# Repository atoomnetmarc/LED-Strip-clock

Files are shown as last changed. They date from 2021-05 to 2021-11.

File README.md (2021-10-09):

# Status

This project is in the idea stage.

Next step would be to test if the new schematic could work before ordering the first PCB.

# Why?

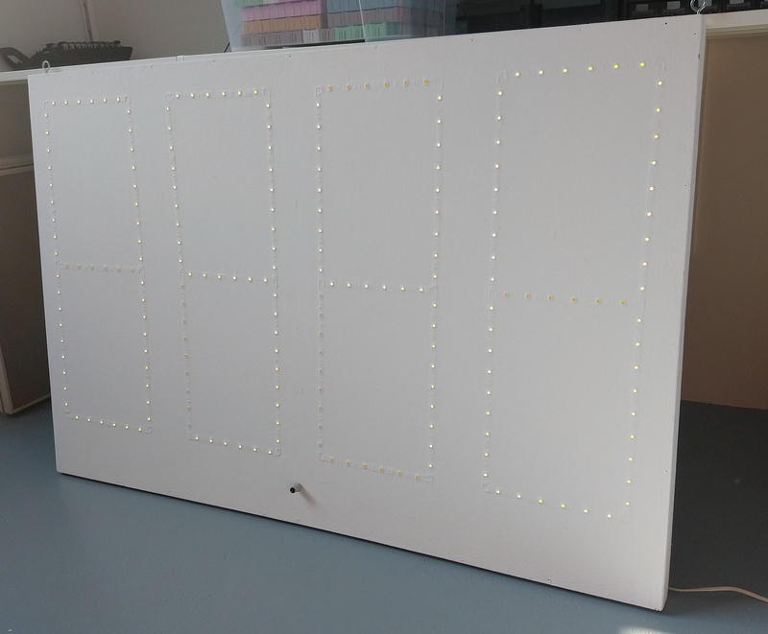
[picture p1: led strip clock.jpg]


I made a huge LED clock with pieces of LED strip in 2013 using an [ATmega328 and DS3231 RTC](ATmega328%20version/). It has been running great and keeping time just fine. Lets break it by upgrading it.

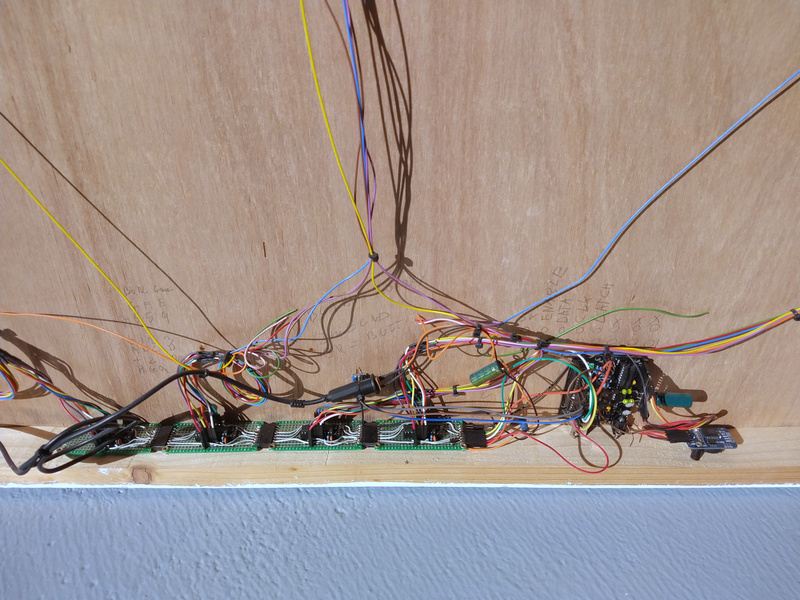
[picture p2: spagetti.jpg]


This project will upgrade the ~~spagetti~~ old circuit to an internet connected LED strip clock neatly on a PCB. The brains will be a Wemos D1 mini and will use NTP to synchronize the time.

# Schematic

The [circuit](Kicad/LED%20Strip%20clock.pdf) recycles the same TPIC6B595 power shift registers and changes the ATmega328 for a ESP8266 and the DS3231 for a DS3231MZ. A 74HCT244 buffer translates between the 3.3V outputs of the ESP8266 and the 5V inputs of the shift register. The original circuit has a rotary encoder to set the light intensity and the current time. The new circuit will only use the rotary encoder to set the light intensity.

Render:

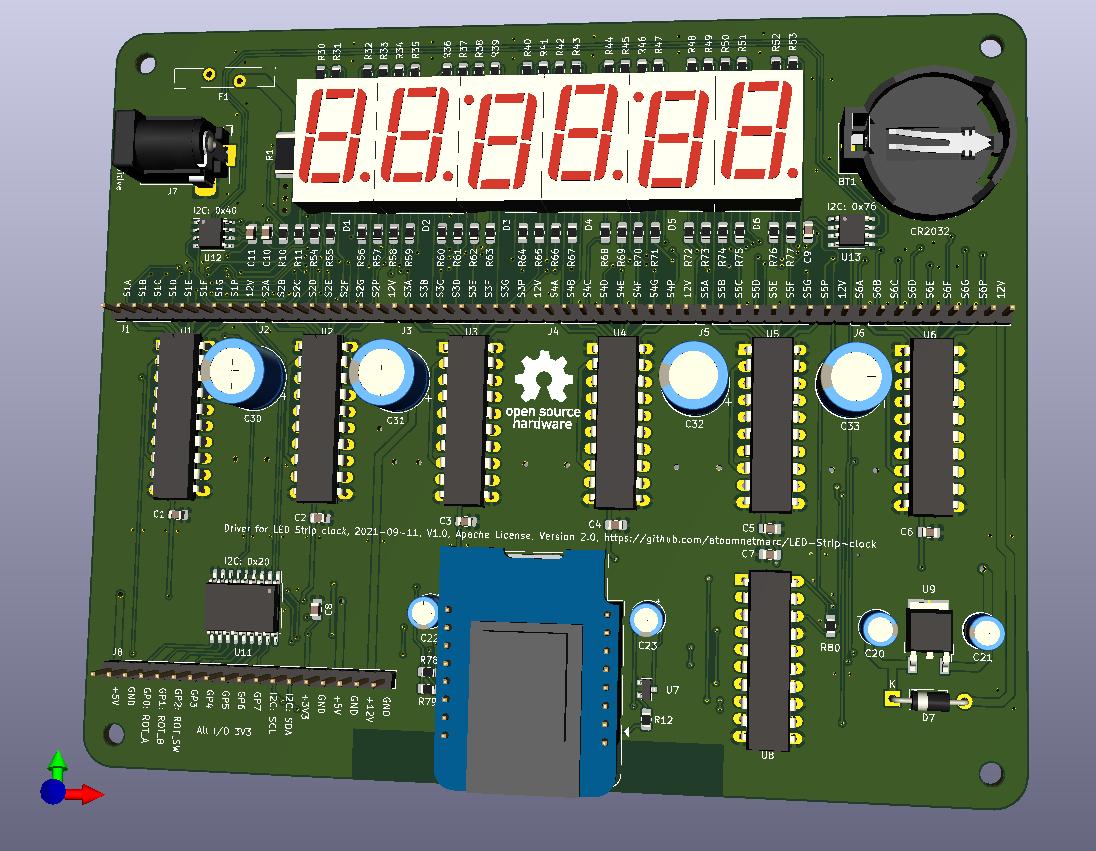
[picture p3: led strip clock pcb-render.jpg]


Real:

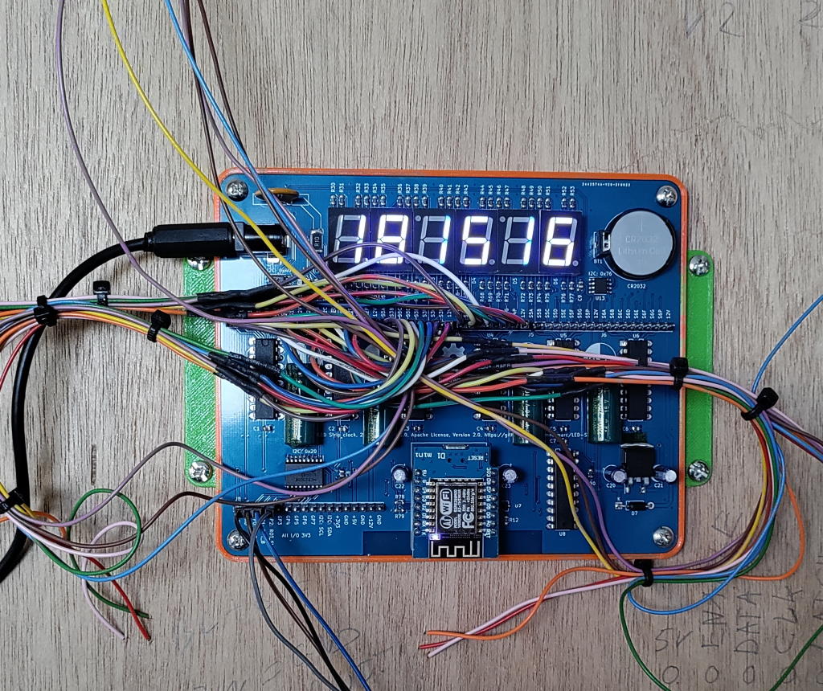
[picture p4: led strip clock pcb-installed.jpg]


My [Kicad library](https://github.com/atoomnetmarc/ATOOMNETKICAD) is used in this project.



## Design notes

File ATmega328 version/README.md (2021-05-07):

**Status**: archived.

This is ye olde code that ran on the ATmega328 board with a DS3231 RTC made in [Atmel studio 6.1](https://www.microchip.com/mplab/avr-support/avr-and-sam-downloads-archive).

# License

Please inspect the individual source files for their respective licenses.

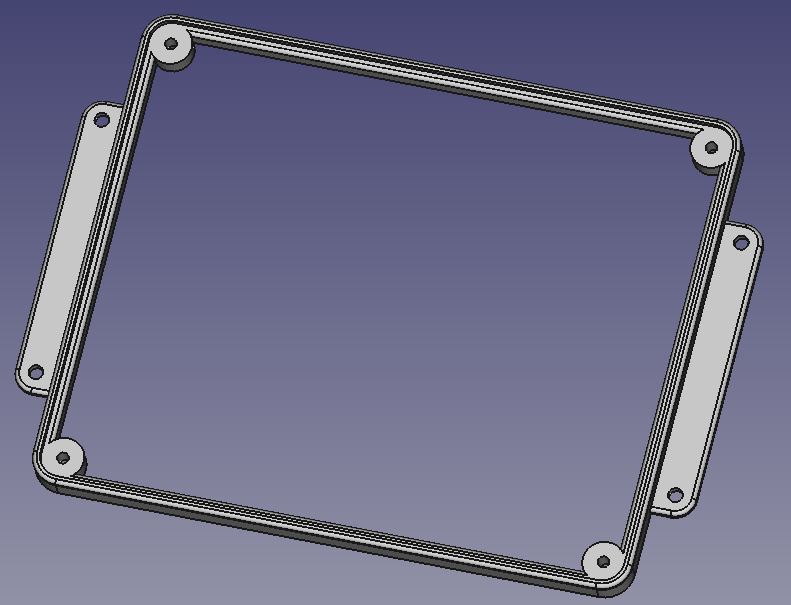
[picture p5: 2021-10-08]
3d/pcb holder.png

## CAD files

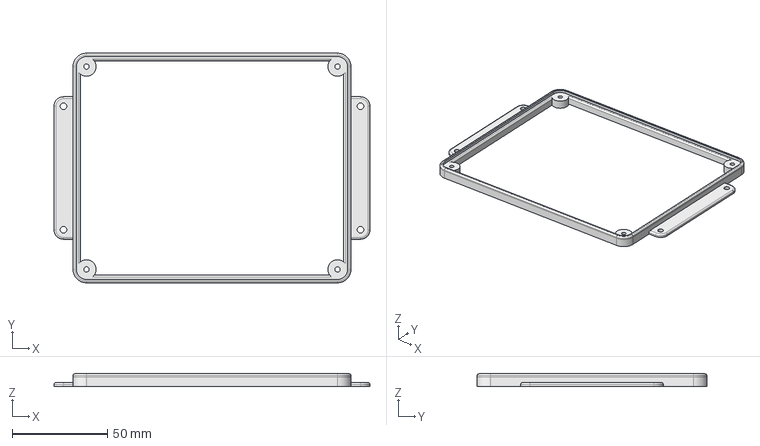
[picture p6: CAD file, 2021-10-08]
3d/pcb holder.FCStd
166.2 x 120.8 x 6.60 mm

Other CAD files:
3d/pcb holder.stl

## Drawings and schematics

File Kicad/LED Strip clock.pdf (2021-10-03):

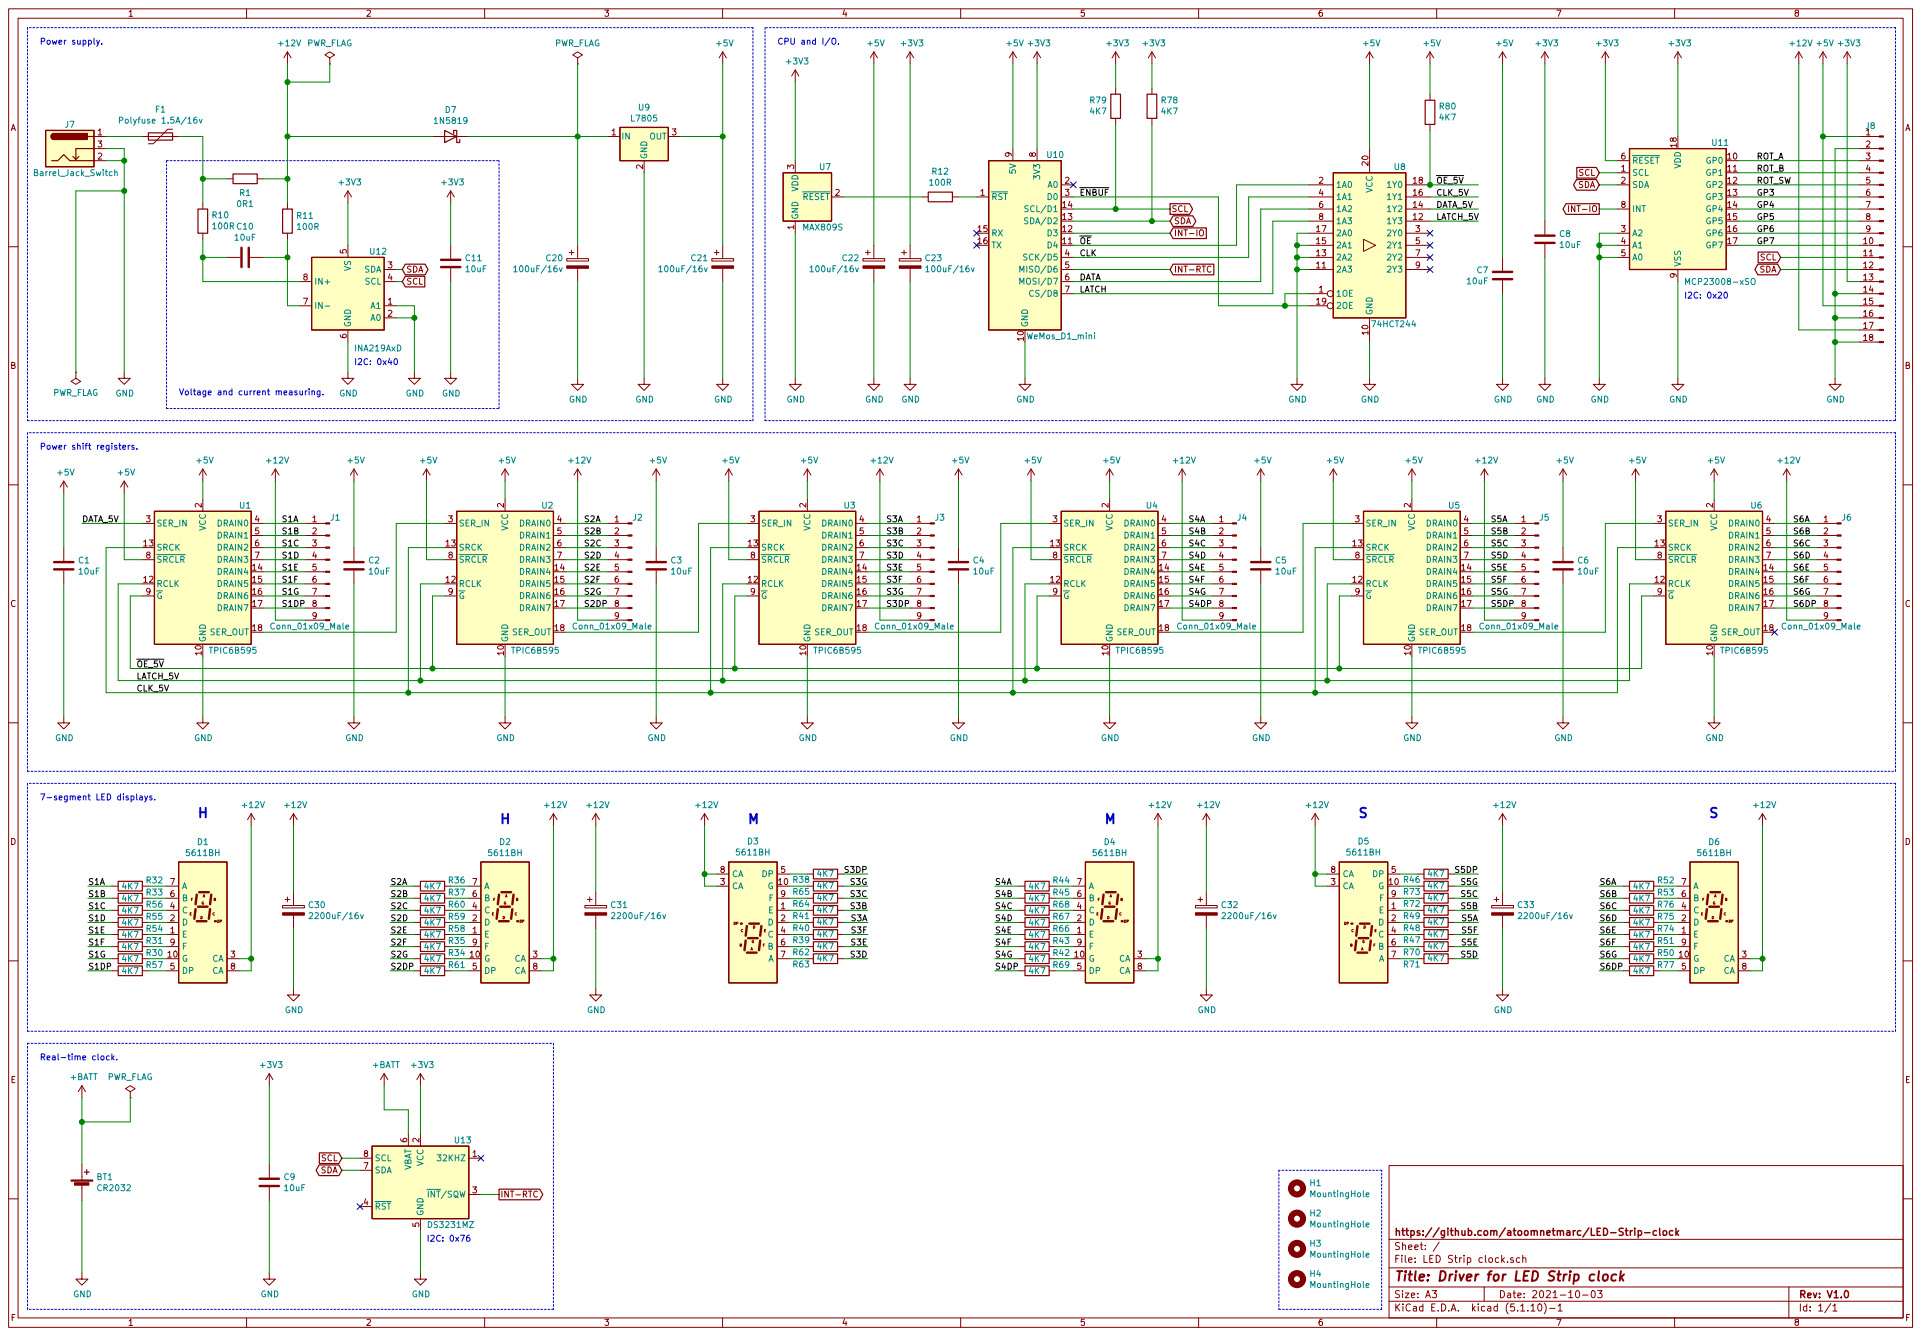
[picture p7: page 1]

Voltage and current measuring.

File: LED Strip clock.sch Sheet: / https://github.com/atoomnetmarc/LED-Strip-clock

Id: 1/1 Title: Driver for LED Strip clock

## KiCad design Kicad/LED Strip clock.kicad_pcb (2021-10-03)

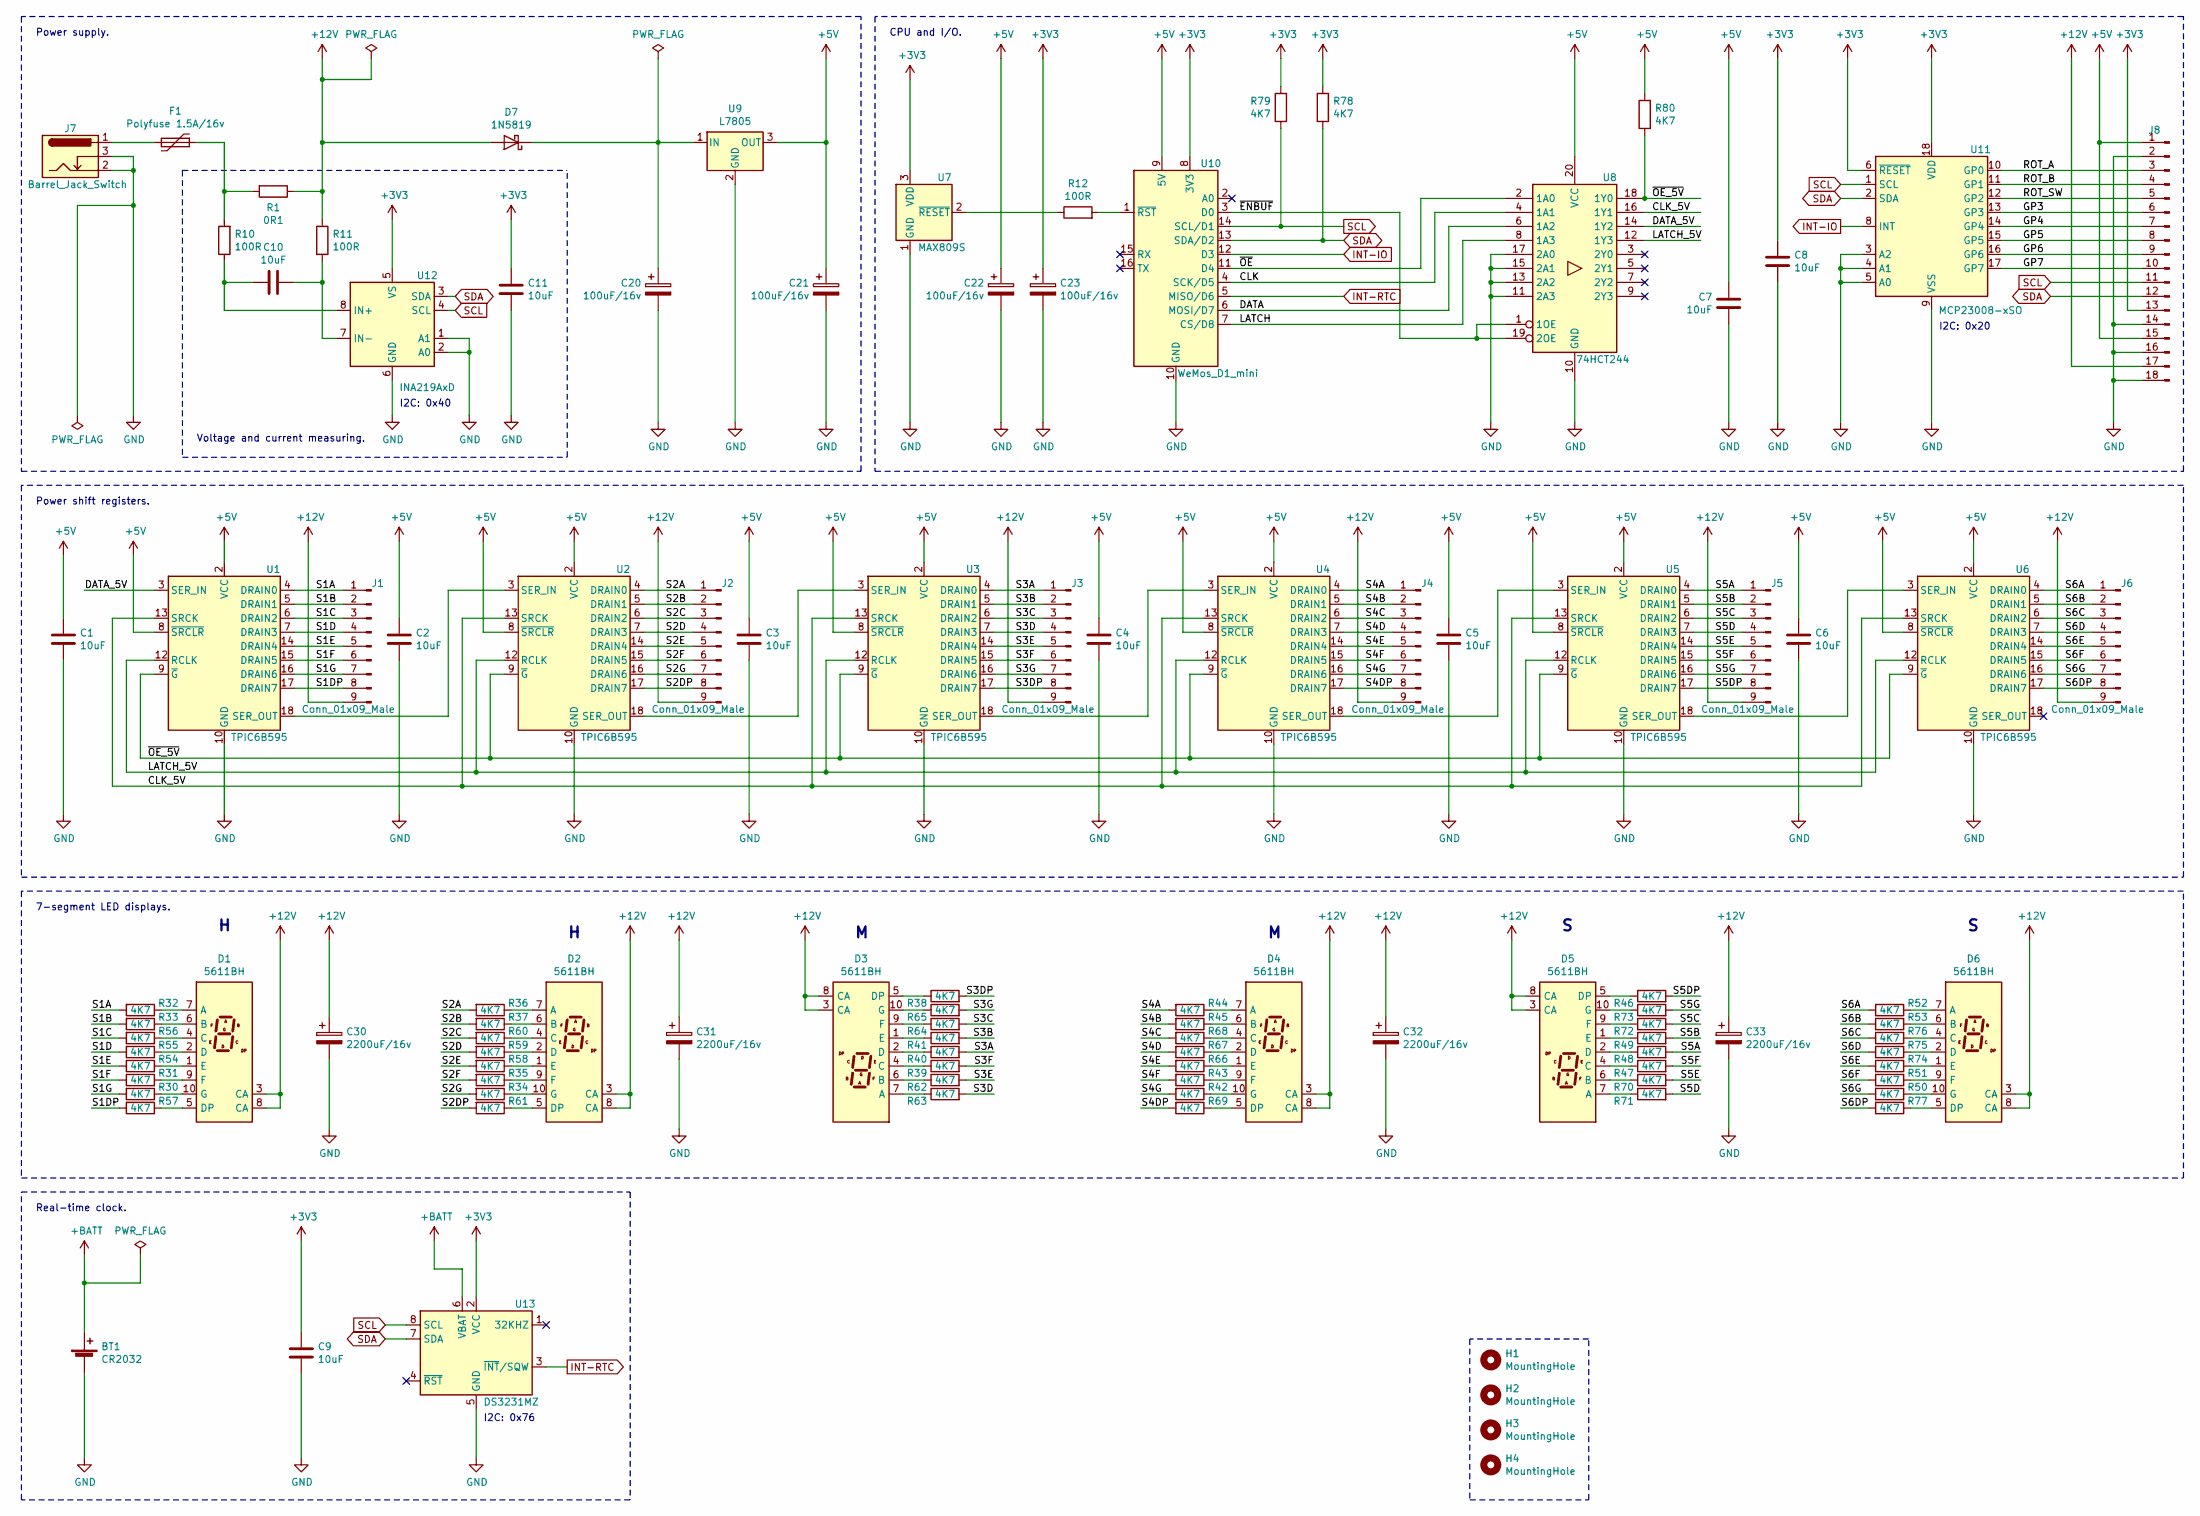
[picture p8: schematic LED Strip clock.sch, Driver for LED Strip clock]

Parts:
BT1: CR2032; BatteryHolder-cr2032
C1, C2, C3, C4, C5, C6, C7, C8, C9, C10, C11: 10uF; C_0805_2012Metric_Pad1.18x1.45mm_HandSolder
C20, C21, C22, C23: 100uF/16v; CP_Radial_D5.0mm_P2.00mm
C30, C31, C32, C33: 2200uF/16v; CP_Radial_D10.0mm_P5.00mm
D1, D2, D3, D4, D5, D6: 5611BH
D7: 1N5819; D_DO-41_SOD81_P10.16mm_Horizontal
F1: Polyfuse 1.5A/16v; Fuse_Bourns_MF-RG1000
H1, H2, H3, H4: MountingHole; MountingHole_3.2mm_M3
J1, J2, J3, J4, J5, J6: Conn_01x09_Male; PinHeader_1x09_P2.54mm_Vertical
J7: Barrel_Jack_Switch; BarrelJack_Horizontal
J8: Conn_01x18_Male; PinHeader_1x18_P2.54mm_Vertical
R1: 0R1; R_2512_6332Metric_Pad1.52x3.35mm_HandSolder
R10, R11, R12: 100R; R_0805_2012Metric_Pad1.20x1.40mm_HandSolder
R30, R31, R32, R33, R34, R35, R36, R37, R38, R39, R40, R41, R42, R43, R44, R45, R46, R47, R48, R49, R50, R51, R52, R53, R54, R55, R56, R57, R58, R59, R60, R61, R62, R63, R64, R65, R66, R67, R68, R69, R70, R71, R72, R73, R74, R75, R76, R77, R78, R79, R80: 4K7; R_0805_2012Metric_Pad1.20x1.40mm_HandSolder
U1, U2, U3, U4, U5, U6: TPIC6B595; DIP-20_W7.62mm_LongPads
U7: MAX809S; SOT-23
U8: 74HCT244; DIP-20_W7.62mm_LongPads
U9: L7805; TO-263-2
U10: WeMos_D1_mini; WEMOS_D1_mini_light
U11: MCP23008-xSO; SOIC-18W_7.5x11.6mm_P1.27mm
U12: INA219AxD; SOIC-8_3.9x4.9mm_P1.27mm
U13: DS3231MZ; SOIC-8_3.9x4.9mm_P1.27mm

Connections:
+3V3: C8.1, C9.1, C11.1, C23.1, J8.13, R78.2, R79.2, U7.3 (VDD), U10.8 (3V3), U11.6 (~RESET), U11.18 (VDD), U12.5 (VS), U13.2 (VCC)
+5V: C1.1, C2.1, C3.1, C4.1, C5.1, C6.1, C7.1, C21.1, C22.1, J8.1, J8.15, R80.2, U1.2 (VCC), U1.8 (~SRCLR), U2.2 (VCC), U2.8 (~SRCLR), U3.2 (VCC), U3.8 (~SRCLR), U4.2 (VCC), U4.8 (~SRCLR), U5.2 (VCC), U5.8 (~SRCLR), U6.2 (VCC), U6.8 (~SRCLR), U8.20 (VCC), U9.3 (OUT), U10.9 (5V)
+12V: C30.1, C31.1, C32.1, C33.1, D1.3 (CA), D1.8 (CA), D2.3 (CA), D2.8 (CA), D3.3 (CA), D3.8 (CA), D4.3 (CA), D4.8 (CA), D5.3 (CA), D5.8 (CA), D6.3 (CA), D6.8 (CA), D7.2 (A), J1.9, J2.9, J3.9, J4.9, J5.9, J6.9, J8.17, R1.1, R11.1
+BATT: BT1.1 (+), U13.6 (VBAT)
/CLK: U8.4 (1A1), U10.4 (SCK/D5)
/CLK_5V: U1.13 (SRCK), U2.13 (SRCK), U3.13 (SRCK), U4.13 (SRCK), U5.13 (SRCK), U6.13 (SRCK), U8.16 (1Y1)
/DATA: U8.6 (1A2), U10.6 (MOSI/D7)
/DATA_5V: U1.3 (SER_IN), U8.14 (1Y2)
/GP3: J8.6, U11.13 (GP3)
/GP4: J8.7, U11.14 (GP4)
/GP5: J8.8, U11.15 (GP5)
/GP6: J8.9, U11.16 (GP6)
/GP7: J8.10, U11.17 (GP7)
/LATCH: U8.8 (1A3), U10.7 (CS/D8)
/LATCH_5V: U1.12 (RCLK), U2.12 (RCLK), U3.12 (RCLK), U4.12 (RCLK), U5.12 (RCLK), U6.12 (RCLK), U8.12 (1Y3)
/ROT_A: J8.3, U11.10 (GP0)
/ROT_B: J8.4, U11.11 (GP1)
/ROT_SW: J8.5, U11.12 (GP2)
/S1A: J1.1, R32.2, U1.4 (DRAIN0)
/S1B: J1.2, R33.2, U1.5 (DRAIN1)
/S1C: J1.3, R56.2, U1.6 (DRAIN2)
/S1D: J1.4, R55.2, U1.7 (DRAIN3)
/S1DP: J1.8, R57.2, U1.17 (DRAIN7)
/S1E: J1.5, R54.2, U1.14 (DRAIN4)
/S1F: J1.6, R31.2, U1.15 (DRAIN5)
/S1G: J1.7, R30.2, U1.16 (DRAIN6)
/S2A: J2.1, R36.2, U2.4 (DRAIN0)
/S2B: J2.2, R37.2, U2.5 (DRAIN1)
/S2C: J2.3, R60.2, U2.6 (DRAIN2)
/S2D: J2.4, R59.2, U2.7 (DRAIN3)
/S2DP: J2.8, R61.2, U2.17 (DRAIN7)
/S2E: J2.5, R58.2, U2.14 (DRAIN4)
/S2F: J2.6, R35.2, U2.15 (DRAIN5)
/S2G: J2.7, R34.2, U2.16 (DRAIN6)
/S3A: J3.1, R40.2, U3.4 (DRAIN0)
/S3B: J3.2, R41.2, U3.5 (DRAIN1)
/S3C: J3.3, R64.2, U3.6 (DRAIN2)
/S3D: J3.4, R63.2, U3.7 (DRAIN3)
/S3DP: J3.8, R38.2, U3.17 (DRAIN7)
/S3E: J3.5, R62.2, U3.14 (DRAIN4)
/S3F: J3.6, R39.2, U3.15 (DRAIN5)
/S3G: J3.7, R65.2, U3.16 (DRAIN6)
/S4A: J4.1, R44.2, U4.4 (DRAIN0)
/S4B: J4.2, R45.2, U4.5 (DRAIN1)
/S4C: J4.3, R68.2, U4.6 (DRAIN2)
/S4D: J4.4, R67.2, U4.7 (DRAIN3)
/S4DP: J4.8, R69.2, U4.17 (DRAIN7)
/S4E: J4.5, R66.2, U4.14 (DRAIN4)
/S4F: J4.6, R43.2, U4.15 (DRAIN5)
/S4G: J4.7, R42.2, U4.16 (DRAIN6)
/S5A: J5.1, R48.2, U5.4 (DRAIN0)
/S5B: J5.2, R49.2, U5.5 (DRAIN1)
/S5C: J5.3, R72.2, U5.6 (DRAIN2)
/S5D: J5.4, R71.2, U5.7 (DRAIN3)
/S5DP: J5.8, R46.2, U5.17 (DRAIN7)
/S5E: J5.5, R70.2, U5.14 (DRAIN4)
/S5F: J5.6, R47.2, U5.15 (DRAIN5)
/S5G: J5.7, R73.2, U5.16 (DRAIN6)
/S6A: J6.1, R52.2, U6.4 (DRAIN0)
/S6B: J6.2, R53.2, U6.5 (DRAIN1)
/S6C: J6.3, R76.2, U6.6 (DRAIN2)
/S6D: J6.4, R75.2, U6.7 (DRAIN3)
/S6DP: J6.8, R77.2, U6.17 (DRAIN7)
/S6E: J6.5, R74.2, U6.14 (DRAIN4)
/S6F: J6.6, R51.2, U6.15 (DRAIN5)
/S6G: J6.7, R50.2, U6.16 (DRAIN6)
/~ENBUF: U8.1 (1OE), U8.19 (2OE), U10.3 (D0)
/~OE: U8.2 (1A0), U10.11 (D4)
/~OE_5V: R80.1, U1.9 (~G), U2.9 (~G), U3.9 (~G), U4.9 (~G), U5.9 (~G), U6.9 (~G), U8.18 (1Y0)
GND: BT1.2 (-), C1.2, C2.2, C3.2, C4.2, C5.2, C6.2, C7.2, C8.2, C9.2, C11.2, C20.2, C21.2, C22.2, C23.2, C30.2, C31.2, C32.2, C33.2, J7.2, J7.3, J8.2, J8.14, J8.16, J8.18, U1.1 (NC), U1.10 (GND), U1.11 (GND), U1.19 (GND), U1.20 (NC), U2.1 (NC), U2.10 (GND), U2.11 (GND), U2.19 (GND), U2.20 (NC), U3.1 (NC), U3.10 (GND), U3.11 (GND), U3.19 (GND), U3.20 (NC), U4.1 (NC), U4.10 (GND), U4.11 (GND), U4.19 (GND), U4.20 (NC), U5.1 (NC), U5.10 (GND), U5.11 (GND), U5.19 (GND), U5.20 (NC), U6.1 (NC), U6.10 (GND), U6.11 (GND), U6.19 (GND), U6.20 (NC), U7.1 (GND), U8.10 (GND), U8.11 (2A3), U8.13 (2A2), U8.15 (2A1), U8.17 (2A0), U9.2 (GND), U10.10 (GND), U11.3 (A2), U11.4 (A1), U11.5 (A0), U11.9 (VSS), U12.1 (A1), U12.2 (A0), U12.6 (GND), U13.5 (GND)
INT-IO: U10.12 (D3), U11.8 (INT)
INT-RTC: U10.5 (MISO/D6), U13.3 (~INT~/SQW)
unnamed: C10.1, R10.1, U12.8 (IN+)
unnamed: C10.2, R11.2, U12.7 (IN-)
unnamed: C20.1, D7.1 (K), U9.1 (IN)
unnamed: D1.1 (E), R54.1
unnamed: D1.2 (D), R55.1
unnamed: D1.4 (C), R56.1
unnamed: D1.5 (DP), R57.1
unnamed: D1.6 (B), R33.1
unnamed: D1.7 (A), R32.1
unnamed: D1.9 (F), R31.1
unnamed: D1.10 (G), R30.1
unnamed: D2.1 (E), R58.1
unnamed: D2.2 (D), R59.1
unnamed: D2.4 (C), R60.1
unnamed: D2.5 (DP), R61.1
unnamed: D2.6 (B), R37.1
unnamed: D2.7 (A), R36.1
unnamed: D2.9 (F), R35.1
unnamed: D2.10 (G), R34.1
unnamed: D3.1 (E), R41.1
unnamed: D3.2 (D), R40.1
unnamed: D3.4 (C), R39.1
unnamed: D3.5 (DP), R38.1
unnamed: D3.6 (B), R62.1
unnamed: D3.7 (A), R63.1
unnamed: D3.9 (F), R64.1
unnamed: D3.10 (G), R65.1
unnamed: D4.1 (E), R66.1
unnamed: D4.2 (D), R67.1
unnamed: D4.4 (C), R68.1
unnamed: D4.5 (DP), R69.1
unnamed: D4.6 (B), R45.1
unnamed: D4.7 (A), R44.1
unnamed: D4.9 (F), R43.1
unnamed: D4.10 (G), R42.1
unnamed: D5.1 (E), R49.1
unnamed: D5.2 (D), R48.1
unnamed: D5.4 (C), R47.1
unnamed: D5.5 (DP), R46.1
unnamed: D5.6 (B), R70.1
unnamed: D5.7 (A), R71.1
unnamed: D5.9 (F), R72.1
unnamed: D5.10 (G), R73.1
unnamed: D6.1 (E), R74.1
unnamed: D6.2 (D), R75.1
unnamed: D6.4 (C), R76.1
unnamed: D6.5 (DP), R77.1
unnamed: D6.6 (B), R53.1
unnamed: D6.7 (A), R52.1
unnamed: D6.9 (F), R51.1
unnamed: D6.10 (G), R50.1
unnamed: F1.1, R1.2, R10.2
unnamed: F1.2, J7.1
unnamed: R12.1, U7.2 (~RESET)
unnamed: R12.2, U10.1 (~RST)
unnamed: U1.18 (SER_OUT), U2.3 (SER_IN)
unnamed: U2.18 (SER_OUT), U3.3 (SER_IN)
unnamed: U3.18 (SER_OUT), U4.3 (SER_IN)
unnamed: U4.18 (SER_OUT), U5.3 (SER_IN)
unnamed: U5.18 (SER_OUT), U6.3 (SER_IN)
SCL: J8.11, R79.1, U10.14 (SCL/D1), U11.1 (SCL), U12.4 (SCL), U13.8 (SCL)
SDA: J8.12, R78.1, U10.13 (SDA/D2), U11.2 (SDA), U12.3 (SDA), U13.7 (SDA)

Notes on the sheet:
I2C: 0x40
I2C: 0x20
Voltage and current measuring.
Power supply.
CPU and I/O.
Power shift registers.
7-segment LED displays.
Real-time clock.
I2C: 0x76

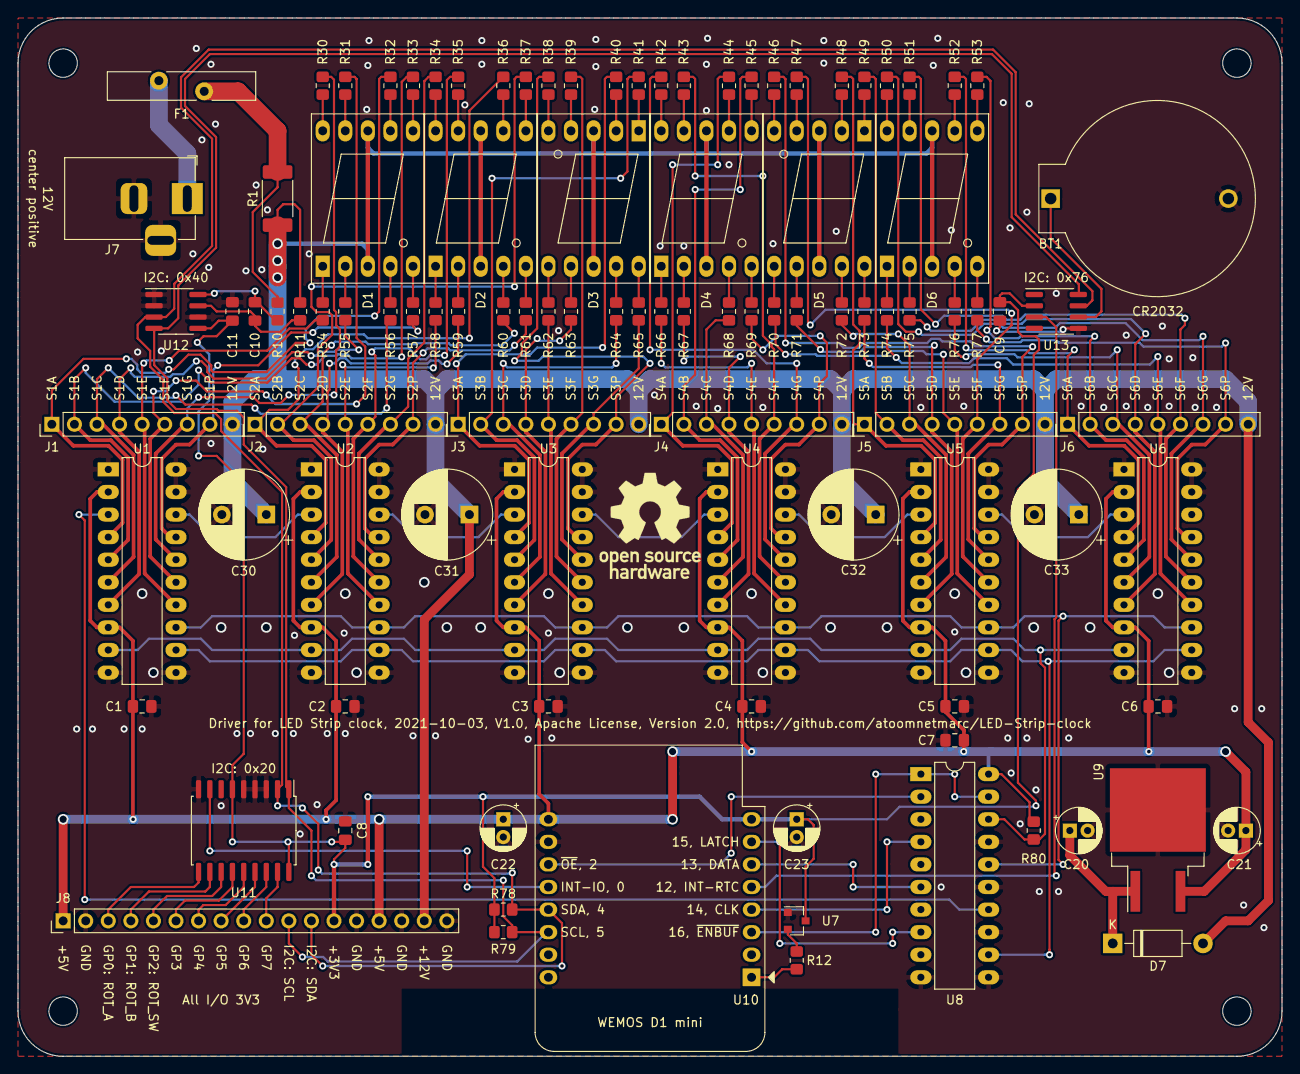
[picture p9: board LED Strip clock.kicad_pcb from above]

Board: 2 copper layers, 142.2 x 116.8 mm, 108 parts (0 on the bottom side), 134 nets.

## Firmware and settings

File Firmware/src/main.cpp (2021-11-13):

/*

Copyright 2021 Marc Ketel
SPDX-License-Identifier: Apache-2.0

*/

#include <sys/time.h>

#include <Arduino.h>

#include <Wire.h>

#include <coredecls.h>
#include <time.h>
#include <TZ.h>

#include "config.h"
#include "wific.h"

void time_is_set(bool from_sntp)
{
    Serial.println("The NTP server was called!");
}

uint32_t sntp_update_delay_MS_rfc_not_less_than_15000 ()
{
  return 24 * 60 * 60 * 1000UL; // 24 hours
}

void setup()
{
    Wire.begin(SDA, SCL);

    Serial.begin(115200);
    Serial.println(F("Booting"));

    settimeofday_cb(time_is_set);
    configTime(TIMEZONE, NTP_SERVER);

    digitalWrite(PIN_BUFFER_NOT_ENABLE, LOW);
    pinMode(PIN_BUFFER_NOT_ENABLE, OUTPUT);

    digitalWrite(PIN_SHIFT_NOT_OUTPUT_ENABLE, HIGH);
    pinMode(PIN_SHIFT_NOT_OUTPUT_ENABLE, OUTPUT);
    analogWriteRange(1023);
    analogWriteFreq(2000);
    delay(500);

    pinMode(PIN_SHIFT_LATCH, OUTPUT);
    pinMode(PIN_SHIFT_CLOCK, OUTPUT);
    pinMode(PIN_SHIFT_DATA, OUTPUT);

    WificSetup();
}

const char digits[] = {
    0b00111111, // 0
    0b00000110, // 1
    0b01011011, // 2
    0b01001111, // 3
    0b01100110, // 4
    0b01101101, // 5
    0b01111101, // 6
    0b00000111, // 7
    0b01111111, // 8
    0b01101111  // 9
};

void loop()
{
    static uint32_t timer = 0;

    int16_t remainingms = 0;

    if (timer <= millis())
    {
        time_t now;
        time(&now);

        struct timeval tv;
        gettimeofday(&tv, NULL);

        int16_t milliseconds = tv.tv_usec / 1000;

        remainingms = 1000 - milliseconds;
        if (remainingms == 0)
            remainingms = 1000;

        timer = millis() + remainingms;

        tm timeInfo;
        localtime_r(&now, &timeInfo);

        digitalWrite(PIN_SHIFT_LATCH, LOW);

        for (uint8_t i = 0; i < 6; i++)
        {
            uint8_t d = 0;

            if (i == 5)
                d = (timeInfo.tm_hour / 10U) % 10;

            if (i == 4)
                d = (timeInfo.tm_hour / 1U) % 10;

            if (i == 3)
                d = (timeInfo.tm_min / 10U) % 10;

            if (i == 2)
                d = (timeInfo.tm_min / 1U) % 10;

            if (i == 1)
                d = (timeInfo.tm_sec / 10U) % 10;

            if (i == 0)
                d = (timeInfo.tm_sec / 1U) % 10;

            shiftOut(PIN_SHIFT_DATA, PIN_SHIFT_CLOCK, MSBFIRST, digits[d]);
        }

        digitalWrite(PIN_SHIFT_LATCH, HIGH);

        static uint8_t single = 0;
        if (single == 0)
        {
            Serial.println("Setting brightness");
            single = 1;
            analogWrite(PIN_SHIFT_NOT_OUTPUT_ENABLE, 950);
        }

        Serial.print(timeInfo.tm_year + 1900);
        Serial.print(F("-"));
        Serial.print(timeInfo.tm_mon);
        Serial.print(F("-"));
        Serial.print(timeInfo.tm_mday);
        Serial.print(F(" "));
        Serial.print(timeInfo.tm_hour);
        Serial.print(F(":"));
        Serial.print(timeInfo.tm_min);
        Serial.print(F(":"));
        Serial.print(timeInfo.tm_sec);
        Serial.print(F("."));
        Serial.print(milliseconds);
        Serial.println();
    }

    WiFicLoop();
}

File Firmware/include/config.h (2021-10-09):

/*

Copyright 2021 Marc Ketel
SPDX-License-Identifier: Apache-2.0

*/

#include <Arduino.h>

#ifndef config_h
#define config_h

extern const char *ssid;
extern const char *password;

extern const char *otapassword;
extern const char *otahostname;

#define PIN_SHIFT_NOT_OUTPUT_ENABLE D4
#define PIN_SHIFT_DATA D7
#define PIN_SHIFT_CLOCK D5
#define PIN_SHIFT_LATCH D8

#define PIN_BUFFER_NOT_ENABLE D0

#define PIN_IO_INT D3
#define PIN_RTC_INT D6

#define PIN_IO_ROT_A 0
#define PIN_IO_ROT_B 1
#define PIN_IO_ROT_SW 2

#endif

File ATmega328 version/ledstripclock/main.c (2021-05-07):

/*

Copyright 2012 Marc Ketel
SPDX-License-Identifier: Apache-2.0

*/

#include "lib.h"

#include <stdio.h>
#include <math.h>
#include <string.h>

#include <avr/io.h>
#include <avr/interrupt.h>
#include <avr/pgmspace.h>
#include <avr/wdt.h>
#include <avr/power.h>
#include <avr/sleep.h>
#include <avr/cpufunc.h>

#include <util/delay.h>

#include "rtc.h"

char command[16];
unsigned int position;
unsigned int data;

uint8_t brightness = 31;
uint8_t const intensity[] PROGMEM = {0,1,2,3,6,8,12,15,20,24,30,35,42,48,56,63,72,80,90,99,110,120,132,143,156,168,182,195,210,224,240,255};
uint8_t const number[] PROGMEM = {0x00, 0x3F, 0x06, 0x5B, 0x4F, 0x66, 0x6D, 0x7D, 0x07, 0x7F, 0x6F};
uint8_t maxBrightness = 0;

uint8_t i, j;
char line[5];

#define STATE_BRIGHTNESS 1
#define STATE_CLOCKSET 2

uint8_t state = STATE_BRIGHTNESS;
uint8_t stateTimeout = 0;

int main(void)
{
  wdt_enable(WDTO_120MS);
	init();

/*
  ds1307Reg_t dateTime;
  getRTC(&dateTime);
  dateTime.ch = 0;
  dateTime.rs = 0;
  dateTime.out = 0;
  dateTime.sqwe = 1;
  dateTime.mode12 = 0;
  setRTC(&dateTime);
*/

  DS3231Ram_t ram;
  getRTCRAM(&ram);
  OCR1A = ram.ocr;

  if (OCR1A > ICR1)
    OCR1A = ICR1;

  for(;;)
  {
	  while(event == 0) {} //Wait for events

		if (event & EV_10Hz)
		{
			event &= ~EV_10Hz;
		}

    if (event & EV_1s)
    {
      event &= ~EV_1s;

      DS3231RegDateTime_t DS3231Reg;
      getRTC(&DS3231Reg);

      memset(line, '0', sizeof(line));
      sprintf_P(line, PSTR("%02d%02d"), DS3231Reg.hours10*10+DS3231Reg.hours1, DS3231Reg.minutes10*10+DS3231Reg.minutes1);

      for(i=0;i<4;i++)
      {
        shiftbuffer[3-i] = pgm_read_byte(&(number[line[i] - 0x2F]));
      }

      shiftOut(shiftbuffer, SHIFTSIZE);

      if (stateTimeout > 1)
      {
        stateTimeout--;
      }
      else
      if (stateTimeout==1)
      {
        state = STATE_BRIGHTNESS;
        stateTimeout = 0;
      }

      /*
      OCR1A += 200;
      _delay_ms(50);
      OCR1A -= 200;
      */

    }


    if (event & EVrotCW)
    {
      event &= ~EVrotCW;

      if (state == STATE_BRIGHTNESS)
      {
        if (OCR1A < ICR1 && OCR1A < 30)
          OCR1A+=1;
        else if (OCR1A < ICR1)
          OCR1A+=100;
        else
          OCR1A = ICR1;

        ram.ocr = OCR1A;
        setRTCRAM(&ram);
      }

      if (state == STATE_CLOCKSET)
      {
        DS3231RegDateTime_t DS3231Reg;
        getRTC(&DS3231Reg);
        addMinute(&DS3231Reg);
        setRTC(&DS3231Reg);

        event |= EV_1s;

        stateTimeout = 60;
      }
    }

    if (event & EVrotCCW)
    {
      event &= ~EVrotCCW;

      if (state == STATE_BRIGHTNESS)
      {
        if (OCR1A <= 30 && OCR1A > 1)
          OCR1A-=1;
        else if (OCR1A > 100)
          OCR1A-=100;
        else
          OCR1A=1;

        ram.ocr = OCR1A;
        setRTCRAM(&ram);
      }

      if (state == STATE_CLOCKSET)
      {
        DS3231RegDateTime_t DS3231Reg;
        getRTC(&DS3231Reg);
        substractMinute(&DS3231Reg);
        setRTC(&DS3231Reg);

        event |= EV_1s;

        stateTimeout = 60;
      }
    }

    if (event & EVrotClick)
    {
      event &= ~EVrotClick;

      if (state == STATE_BRIGHTNESS)
        state = STATE_CLOCKSET;
      else
        state = STATE_BRIGHTNESS;
    }


     wdt_reset();
  }
}

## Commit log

2021-08-06 Changed INA219AxDCN to INA219AxD.
    [LED Strip clock.kicad_pcb, LED Strip clock.sch]
2021-08-06 New render
    [LED Strip clock.kicad_pcb]
2021-08-30 Fixed power-on flash of digits.
    [LED Strip clock.kicad_pcb, LED Strip clock.sch]
2021-08-30 Minor schematic tweaks.
    [LED Strip clock.sch]
2021-09-11 Change board layout. Add RTC. Add seconds LED display.
    [LED Strip clock.kicad_pcb, LED Strip clock.sch]
2021-09-21 Generate gerber and BOM.
    [LED Strip clock-B_Cu.gbl, LED Strip clock-B_Mask.gbs, LED Strip clock-B_Paste.gbp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]
2021-10-03 Change footprint of 7805 to D2PAK.
    [LED Strip clock-B_Cu.gbl, LED Strip clock-B_Mask.gbs, LED Strip clock-B_Paste.gbp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]
2021-10-03 Add output files.
    [LED Strip clock-B_Cu.gbl, LED Strip clock-B_Mask.gbs, LED Strip clock-B_Paste.gbp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]
2021-10-08 Add pcb holder.
    [pcb holder.FCStd, pcb holder.stl]
2021-10-09 Add photo of real board.
2026-10-24 Add INA219 power monitoring with 'power' serial command and web UI status.
2026-10-25 Add rotary encoder control via MCP23008 with display refactor, brightness clamping (min 1%) and live brightness preview on the display

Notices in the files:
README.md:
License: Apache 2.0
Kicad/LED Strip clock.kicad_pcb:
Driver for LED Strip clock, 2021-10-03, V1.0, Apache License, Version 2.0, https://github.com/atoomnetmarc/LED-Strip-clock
